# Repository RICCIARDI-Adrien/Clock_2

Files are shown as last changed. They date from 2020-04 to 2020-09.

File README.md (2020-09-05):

# Clock 2

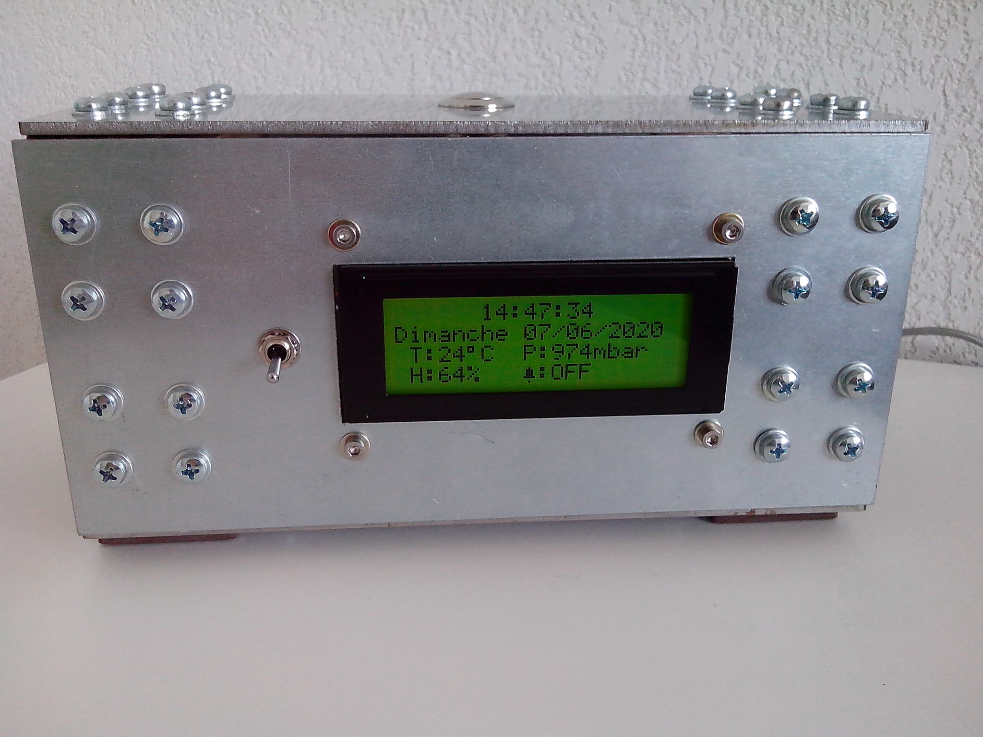
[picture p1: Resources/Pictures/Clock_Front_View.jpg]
Clock 2


Improved digital clock. First generation is [here](https://github.com/RICCIARDI-Adrien/Clock).  

New features :
* Improved temperature sensor.
* Humidity sensor.
* Pressure sensor.
* High accuracy temperature-compensated RTC.
* More compact, more industrial and more robust casing.
* A really simple interface made of 3 buttons to configure all clock settings (no more configuration through USB).

## Firmware

Microchip XC8 version 2.20 or above is required to build the firmware. Previous XC8 versions will work but the Celsius degree unit won't be displayed. This is due to a bug in XC8 escaped string characters parsing.

On a Linux system with XC8 installed and added to `PATH`, enter the following lines :
```
cd <repository directory>/Software
make
```

Resulting firmware file is `Firmware.hex`.

## Photo gallery

### PCB

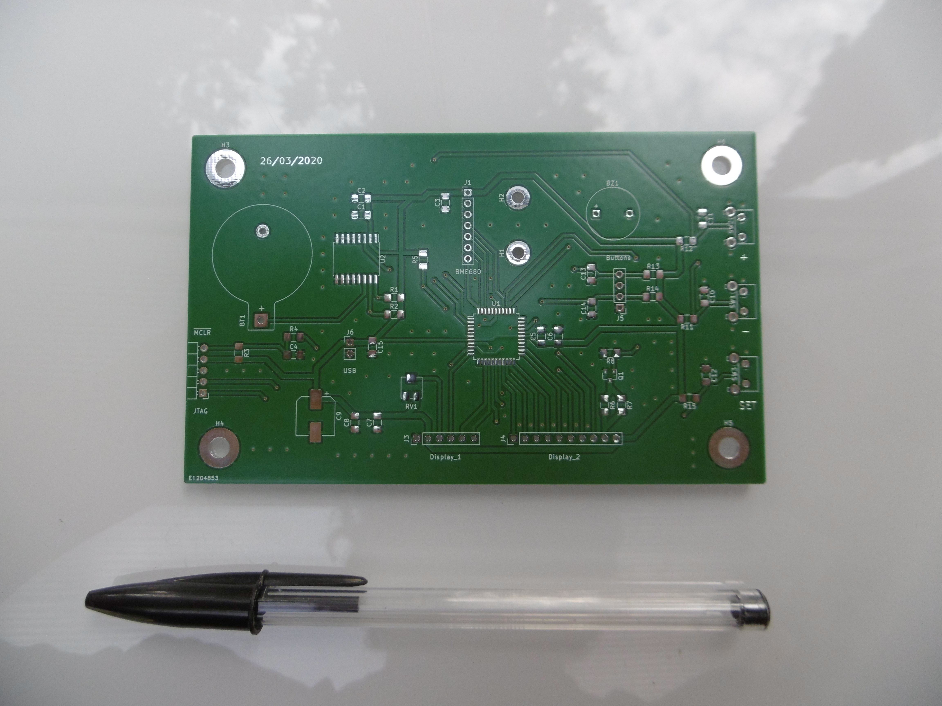
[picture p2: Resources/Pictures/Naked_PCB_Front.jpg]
Naked PCB front

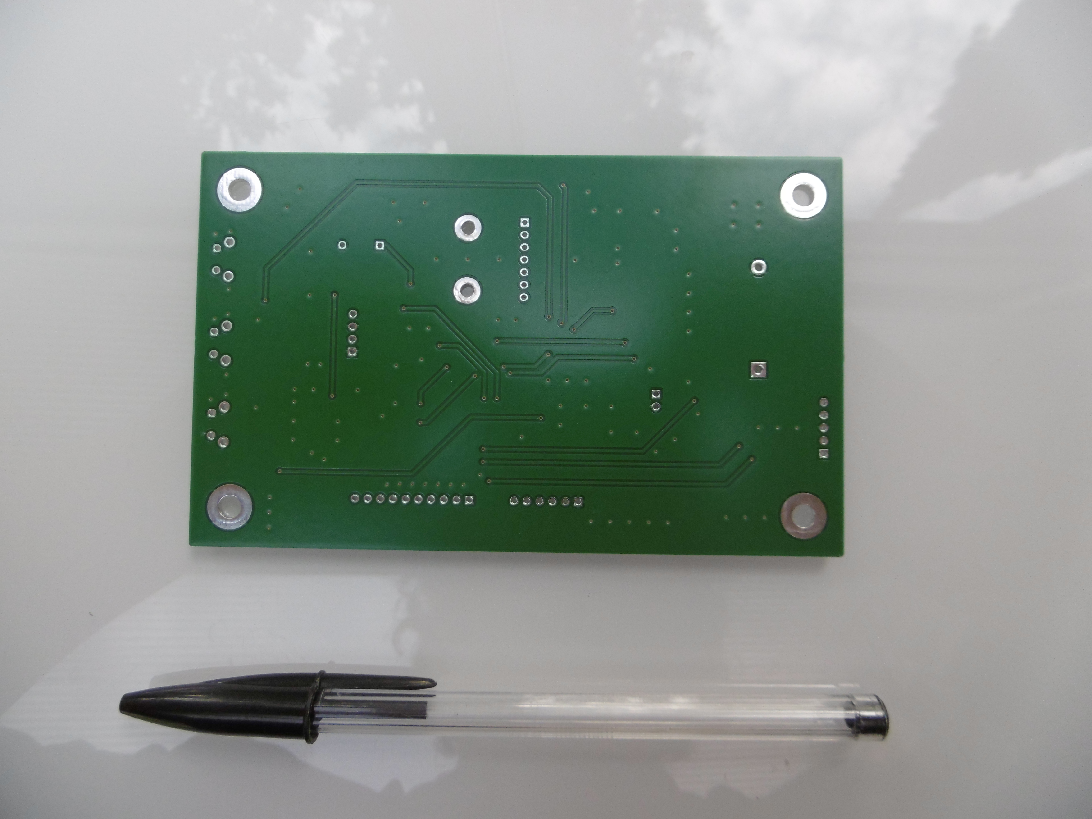
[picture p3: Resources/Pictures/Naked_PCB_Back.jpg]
Naked PCB back


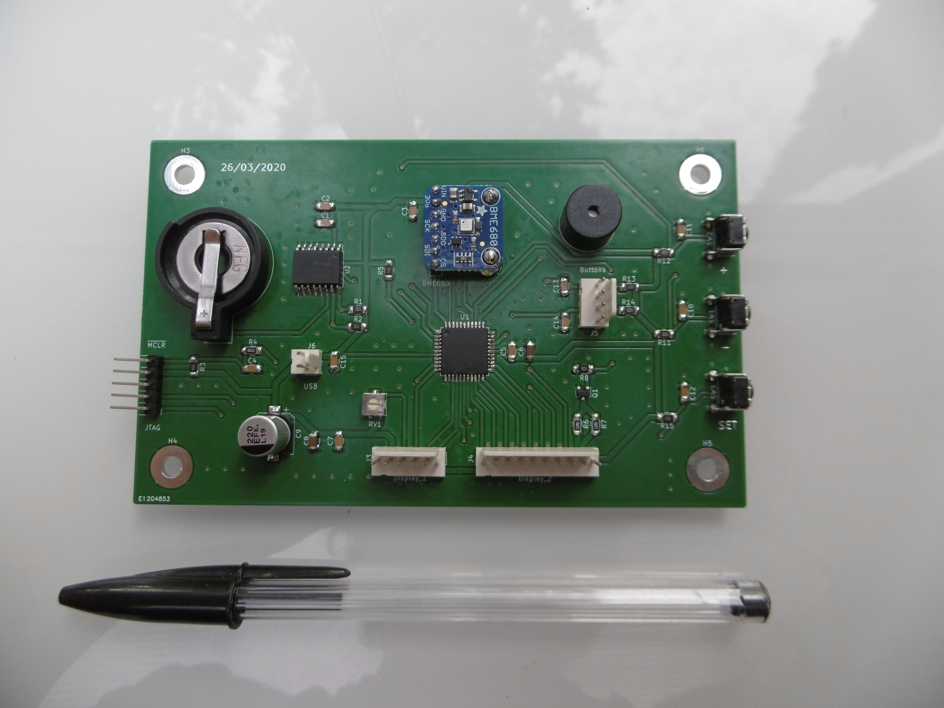
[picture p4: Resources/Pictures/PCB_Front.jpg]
PCB front

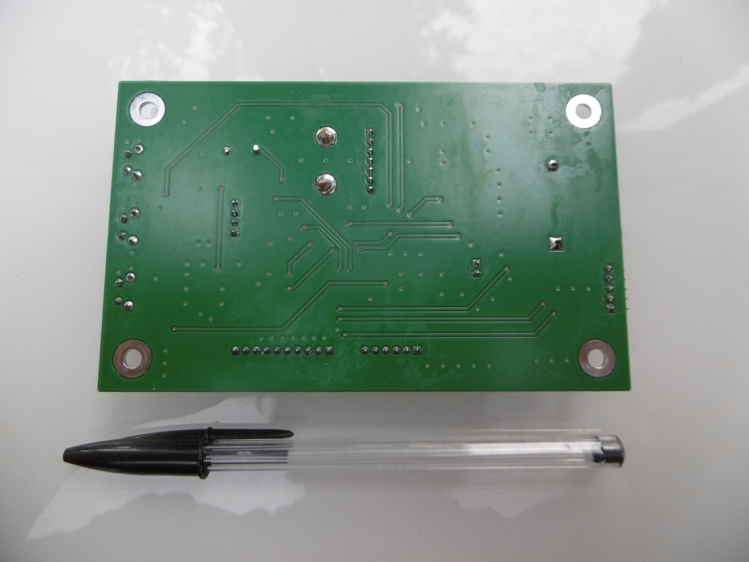
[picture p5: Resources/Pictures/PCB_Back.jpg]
PCB back


### Display

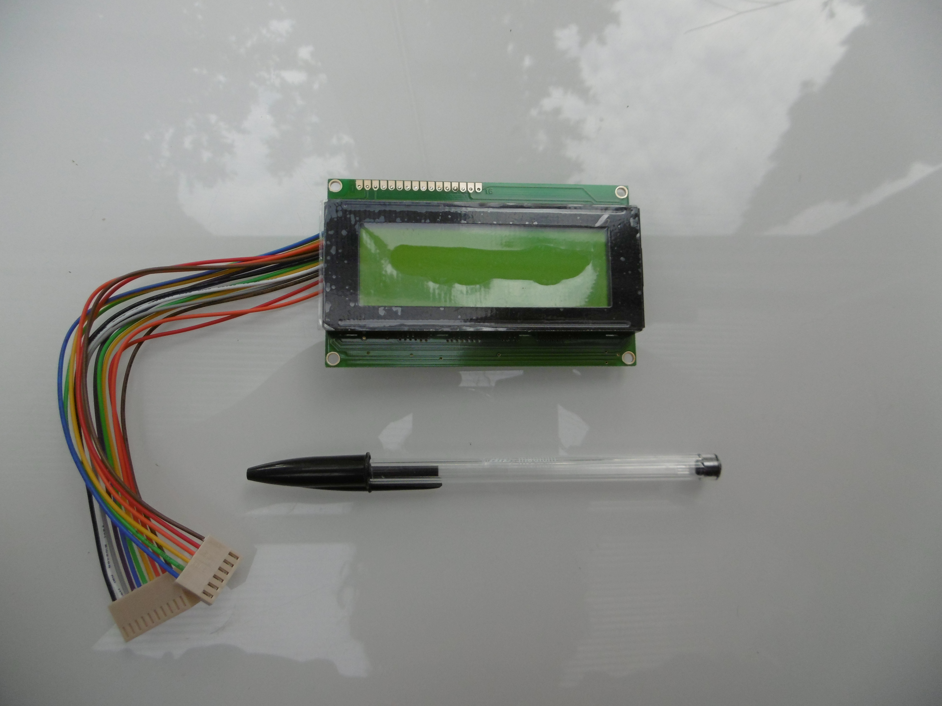
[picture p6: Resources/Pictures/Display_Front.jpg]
Display front

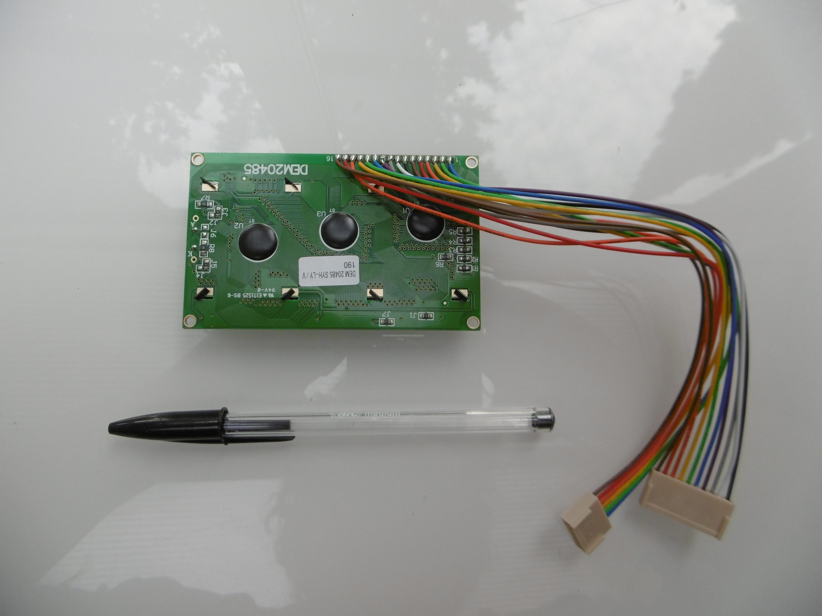
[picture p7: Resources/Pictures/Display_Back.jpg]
Display back


### Casing

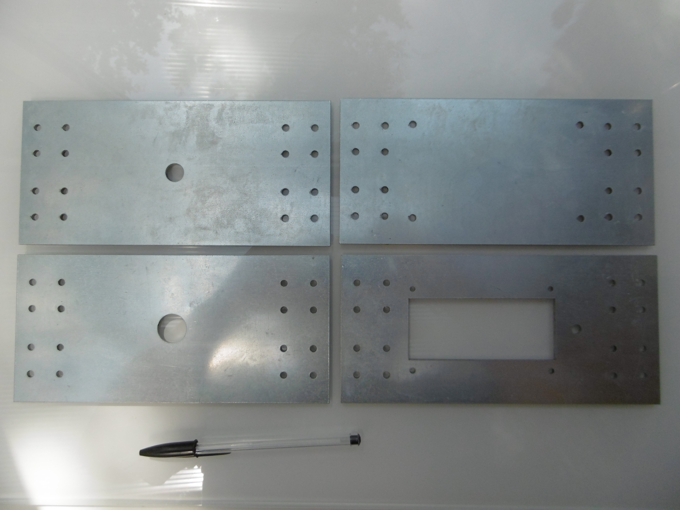
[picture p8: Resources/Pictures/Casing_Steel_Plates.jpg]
Casing steel plates


### Finished clock

Clock front view

Alarm stopping and display backlight button :
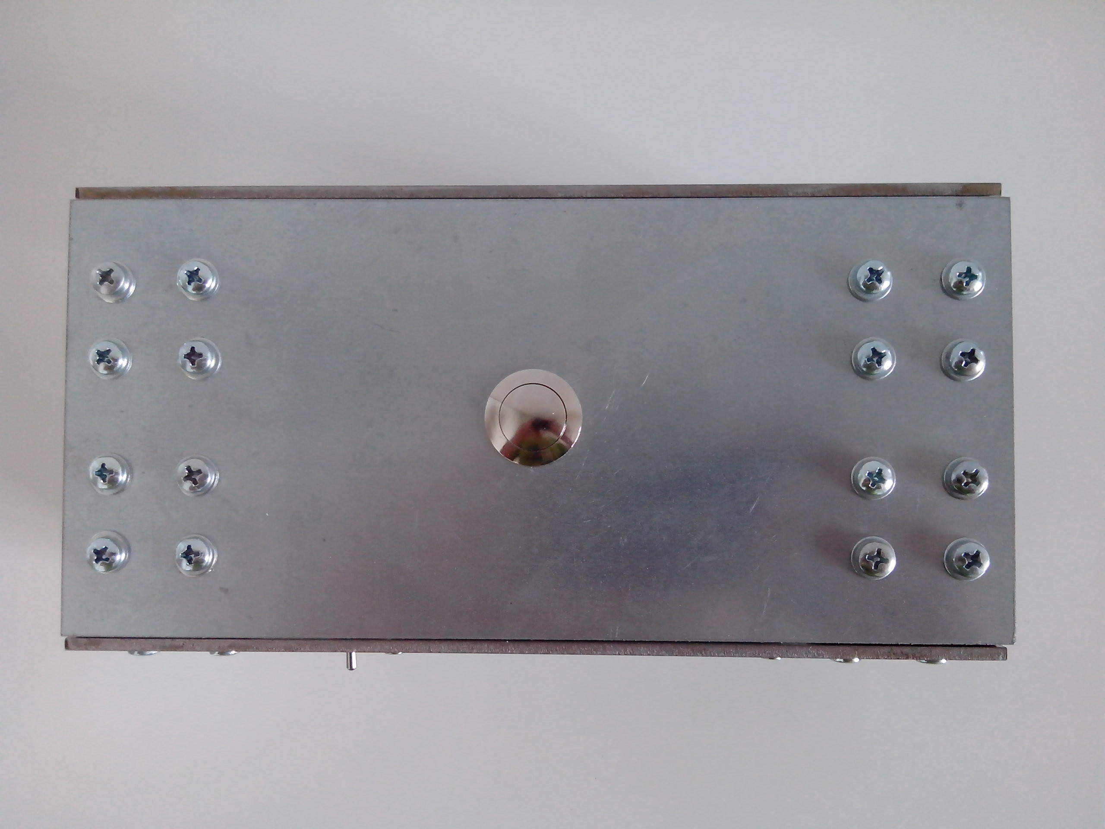
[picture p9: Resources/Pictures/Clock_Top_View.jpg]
Clock top view


Power supply USB connector :
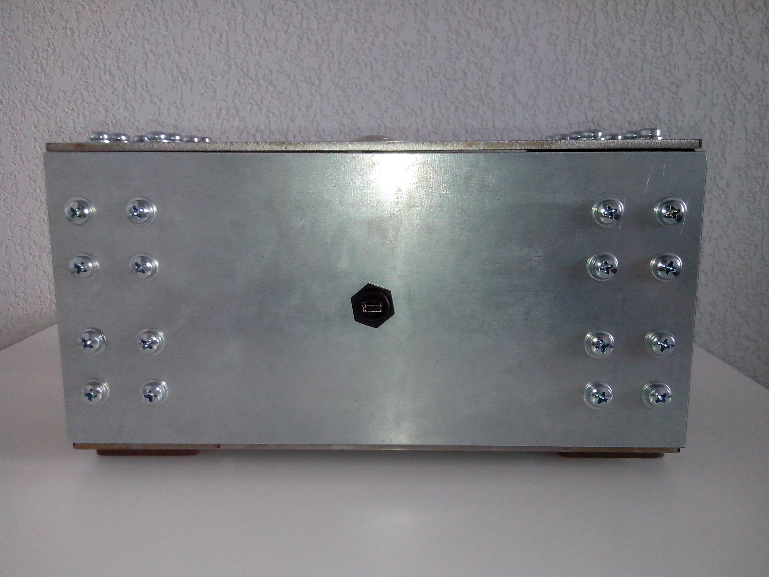
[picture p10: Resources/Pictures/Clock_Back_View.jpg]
Clock back view


Bottom protection pads :
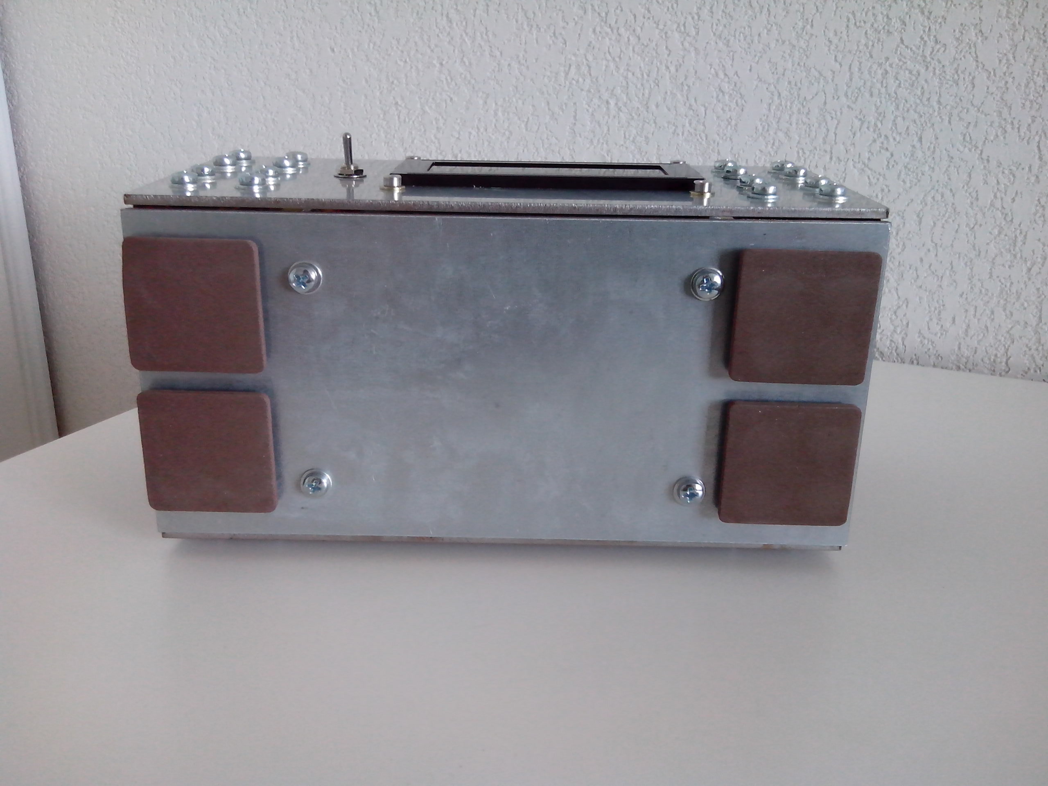
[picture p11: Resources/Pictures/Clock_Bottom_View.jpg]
Clock bottom view


Internal view (backup battery not yet fitted) :
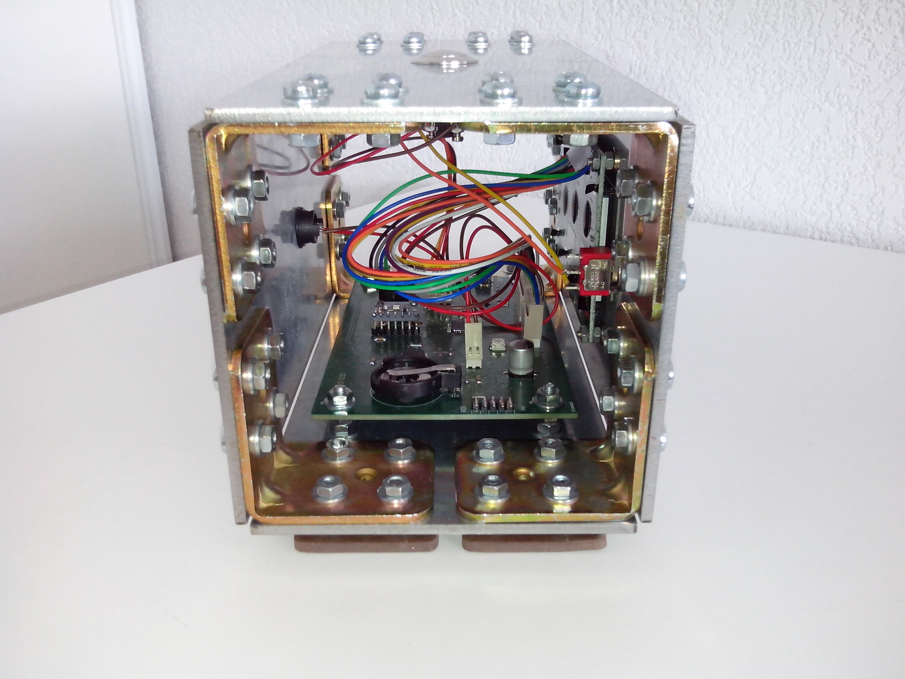
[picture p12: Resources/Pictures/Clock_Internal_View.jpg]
Clock internal view


## Views

### Main

```
+--------------------+
|      11:16:23      |
|Jeudi    19/03/2020 |
| T:23°C  P:1112mBar |
| H:68%   A:OFF      |
+--------------------+
```

```
+--------------------+
|       0:37:11      |
|Dimanche 06/09/2020 |
| T:27°C  P:983mBar  |
| H:50%   A:ON(08:30)|
+--------------------+
```

'A' stands for a bell symbol representing the current alarm state (enabled or disabled).

### Statistics

Press `+` button to reach temperature view.  
Press `-` button to reach humidity view (these views can be accessed in reverse order).

```
+--------------------+
|---- TEMPERATURE ---|
|Minimum : 23°C      |
|Maximum : 15°C      |
|                    |
+--------------------+
```

Press `Set` or `-` button to return to main view.  
Press `+` button to go to pressure view.

```
+--------------------+
|----- PRESSION -----|
|Minimum : 980mbar   |
|Maximum : 1002mbar  |
|                    |
+--------------------+
```

Press `Set` to immediately return to main view.  
Press `-` button to return to temperature view.  
Press `+` button to go to humidity view.

```
+--------------------+
|----- HUMIDITE -----|
|Minimum : 57%       |
|Maximum : 59%       |
|                    |
+--------------------+
```

Press `Set` or `+` button to return to main view.  
Press `-` button to return to pression view.

### Settings

Press `Set` button to reach this view.

```
+--------------------+
|-> Régler alarme    |
|   Régler heure     |
|   Régler date      |
|       Retour       |
+--------------------+
```
Select a menu entry using `+` and `-` buttons, then press `Set` button.

### Set alarm

```
+--------------------+
|--- HEURE ALARME ---|
| Heure : 7          |
| + et - pour régler |
| SET pour continuer |
+--------------------+
```
Press `+` and `-` buttons to choose an hour, then press `Set` button to continue.

```
+--------------------+
|-- MINUTES ALARME --|
| Minutes : 30       |
| + et - pour régler |
| SET pour continuer |
+--------------------+
```
Press `+` and `-` buttons to choose minutes value, then press `Set` button to return to settings menu.

### Set time

```
+--------------------+
|--- REGLER HEURE ---|
| Heure : 11         |
| + et - pour régler |
| SET pour continuer |
+--------------------+
```
Press `+` and `-` buttons to choose an hour, then press `Set` button to continue.

```
+--------------------+
|-- REGLER MINUTES --|
| Minutes : 26       |
| + et - pour régler |
| SET pour continuer |
+--------------------+
```
Press `+` and `-` buttons to choose minutes value, then press `Set` button to continue.

```
+--------------------+
|- REGLER SECONDES --|
| Secondes : 47      |
| + et - pour régler |
| SET pour continuer |
+--------------------+
```
Press `+` and `-` buttons to choose seconds value, then press `Set` button to return to settings menu.

### Set date

```
+--------------------+
|--- REGLER JOUR ----|
| Jour : 14          |
| + et - pour régler |
| SET pour continuer |
+--------------------+
```
Press `+` and `-` buttons to choose a day, then press `Set` button to continue.

```
+--------------------+
|--- REGLER MOIS ----|
| Mois : 3           |
| + et - pour régler |
| SET pour continuer |
+--------------------+
```
Press `+` and `-` buttons to choose a month, then press `Set` button to continue.

```
+--------------------+
|--- REGLER ANNEE ---|
| Année : 2020       |
| + et - pour régler |
| SET pour continuer |
+--------------------+
```
Press `+` and `-` buttons to choose a year, then press `Set` button to return to settings menu.

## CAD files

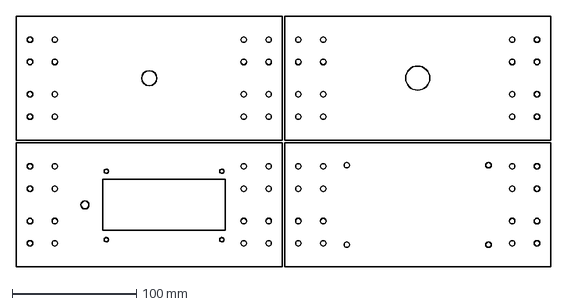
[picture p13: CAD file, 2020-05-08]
Casing/Casing.dxf
430.0 x 202.0 mm

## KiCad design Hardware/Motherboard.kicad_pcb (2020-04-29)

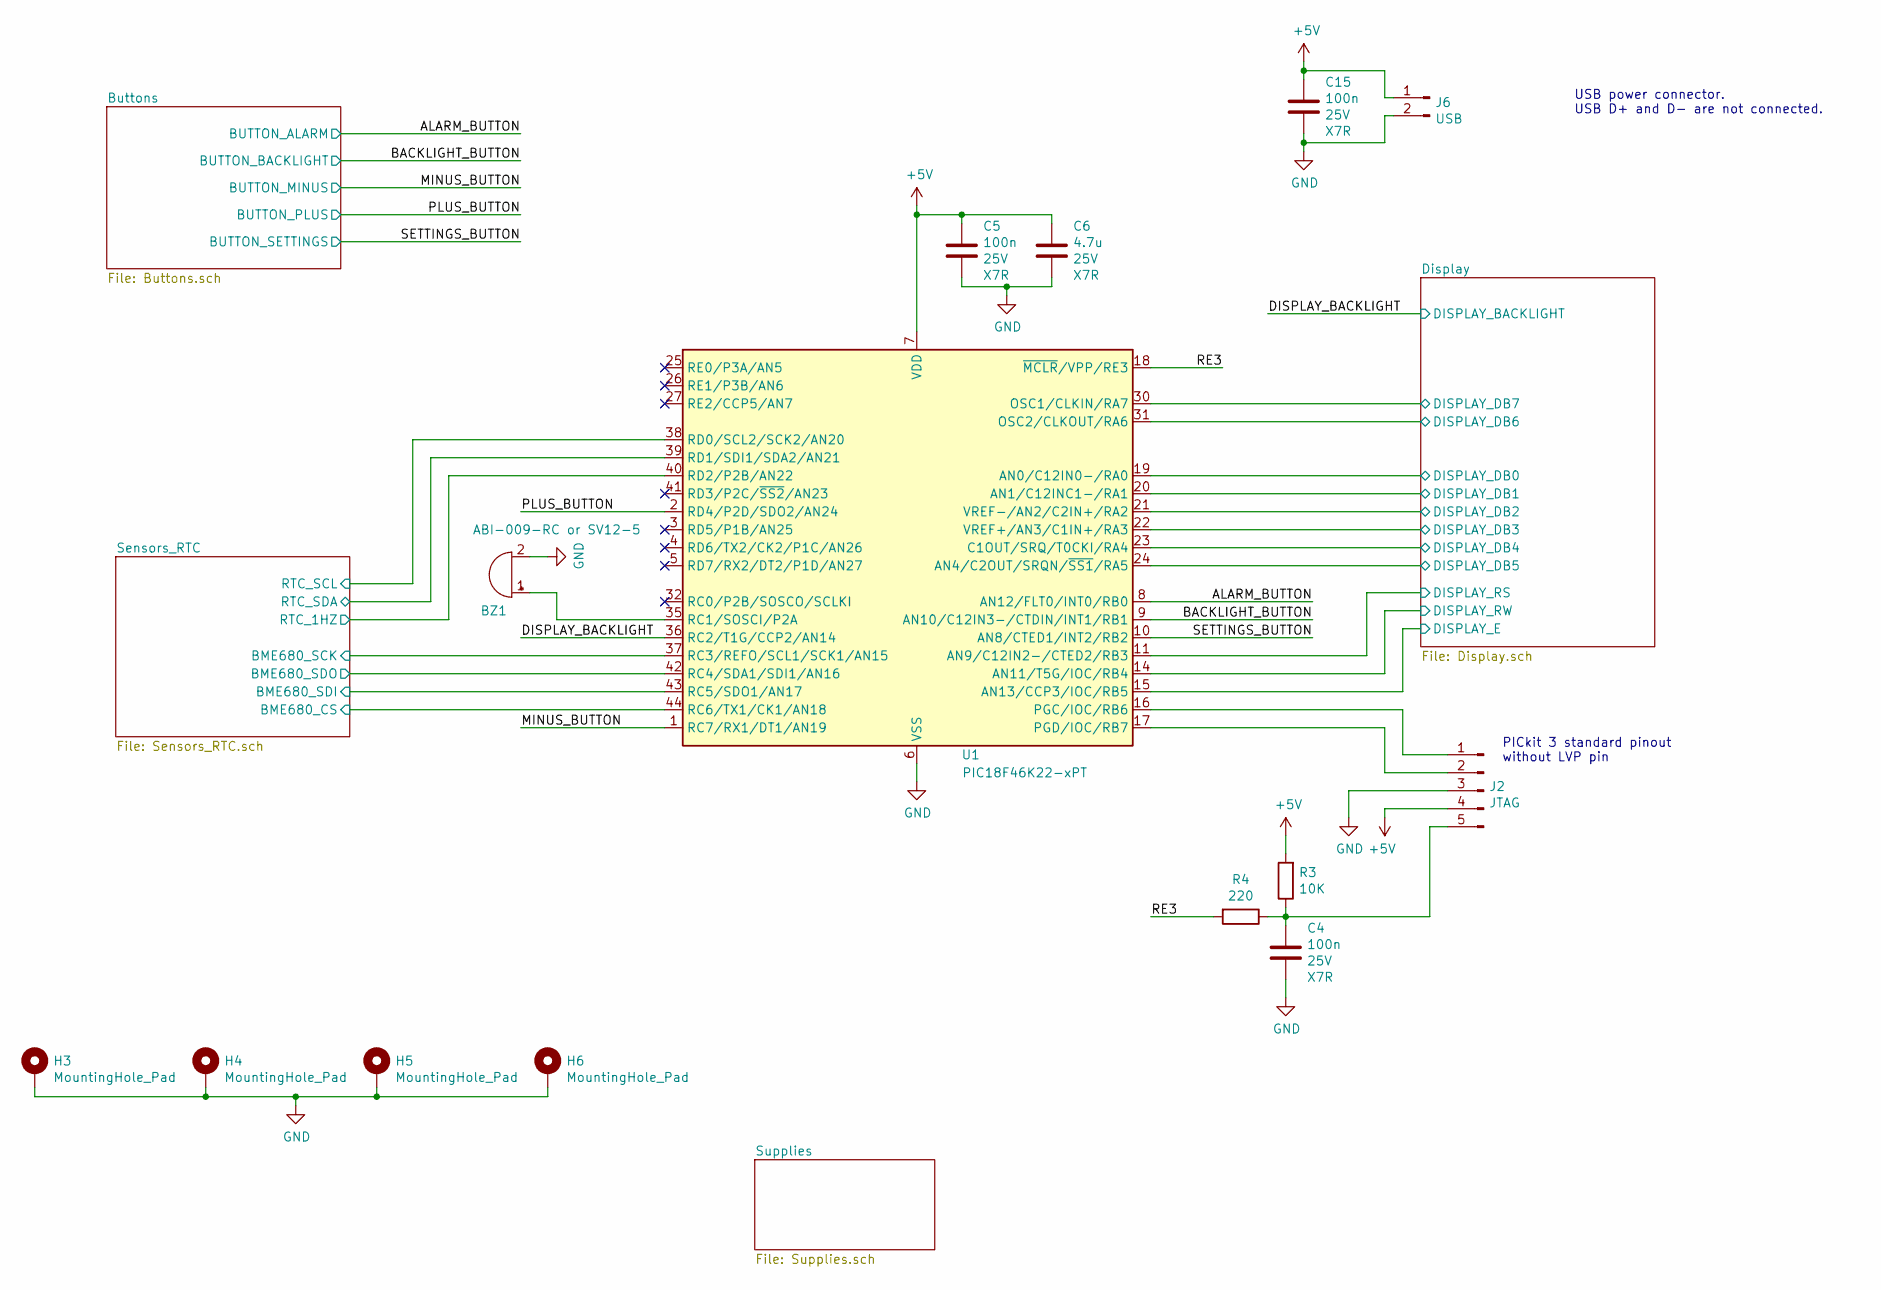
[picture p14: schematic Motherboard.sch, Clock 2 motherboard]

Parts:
BZ1: ABI-009-RC or SV12-5; MagneticBuzzer_ProSignal_ABI-009-RC
C4, C5, C15: 100n; C_1206_3216Metric_Pad1.42x1.75mm_HandSolder
C6: 4.7u; C_1206_3216Metric_Pad1.42x1.75mm_HandSolder
H3, H4, H5, H6: MountingHole_Pad; MountingHole_4.5mm_Pad
J2: JTAG; PinHeader_1x05_P2.54mm_Horizontal
J6: USB; PinHeader_1x02_P2.54mm_Vertical
R3: 10K; R_1206_3216Metric_Pad1.42x1.75mm_HandSolder
R4: 220; R_1206_3216Metric_Pad1.42x1.75mm_HandSolder
U1: PIC18F46K22-xPT; TQFP-44_10x10mm_P0.8mm

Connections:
+5V: C5.1, C6.1, C15.1, J2.4, J6.1, R3.2, U1.7 (VDD), U1.28 (VDD); also elsewhere on the board
/ALARM_BUTTON: U1.8 (AN12/FLT0/INT0/RB0); also elsewhere on the board
/BACKLIGHT_BUTTON: U1.9 (AN10/C12IN3-/CTDIN/INT1/RB1); also elsewhere on the board
/DISPLAY_BACKLIGHT: U1.36 (RC2/T1G/CCP2/AN14); also elsewhere on the board
/Display/DISPLAY_DB0: U1.19 (AN0/C12IN0-/RA0); also elsewhere on the board
/Display/DISPLAY_DB1: U1.20 (AN1/C12INC1-/RA1); also elsewhere on the board
/Display/DISPLAY_DB2: U1.21 (VREF-/AN2/C2IN+/RA2); also elsewhere on the board
/Display/DISPLAY_DB3: U1.22 (VREF+/AN3/C1IN+/RA3); also elsewhere on the board
/Display/DISPLAY_DB4: U1.23 (C1OUT/SRQ/T0CKI/RA4); also elsewhere on the board
/Display/DISPLAY_DB5: U1.24 (AN4/C2OUT/SRQN/~SS1~/RA5); also elsewhere on the board
/Display/DISPLAY_DB6: U1.31 (OSC2/CLKOUT/RA6); also elsewhere on the board
/Display/DISPLAY_DB7: U1.30 (OSC1/CLKIN/RA7); also elsewhere on the board
/Display/DISPLAY_E: U1.15 (AN13/CCP3/IOC/RB5); also elsewhere on the board
/Display/DISPLAY_RS: U1.11 (AN9/C12IN2-/CTED2/RB3); also elsewhere on the board
/Display/DISPLAY_RW: U1.14 (AN11/T5G/IOC/RB4); also elsewhere on the board
/MINUS_BUTTON: U1.1 (RC7/RX1/DT1/AN19); also elsewhere on the board
/PLUS_BUTTON: U1.2 (RD4/P2D/SDO2/AN24); also elsewhere on the board
/RE3: R4.2, U1.18 (~MCLR~/VPP/RE3)
/SETTINGS_BUTTON: U1.10 (AN8/CTED1/INT2/RB2); also elsewhere on the board
/Sensors_RTC/BME680_CS: U1.44 (RC6/TX1/CK1/AN18); also elsewhere on the board
/Sensors_RTC/BME680_SCK: U1.37 (RC3/REFO/SCL1/SCK1/AN15); also elsewhere on the board
/Sensors_RTC/BME680_SDI: U1.43 (RC5/SDO1/AN17); also elsewhere on the board
/Sensors_RTC/BME680_SDO: U1.42 (RC4/SDA1/SDI1/AN16); also elsewhere on the board
/Sensors_RTC/RTC_1HZ: U1.40 (RD2/P2B/AN22); also elsewhere on the board
/Sensors_RTC/RTC_SCL: U1.38 (RD0/SCL2/SCK2/AN20); also elsewhere on the board
/Sensors_RTC/RTC_SDA: U1.39 (RD1/SDI1/SDA2/AN21); also elsewhere on the board
GND: BZ1.2 (+), C4.2, C5.2, C6.2, C15.2, H3.1, H4.1, H5.1, H6.1, J2.3, J6.2, U1.6 (VSS), U1.29 (VSS); also elsewhere on the board
unnamed: BZ1.1 (-), U1.35 (RC1/SOSCI/P2A)
unnamed: C4.1, J2.5, R3.1, R4.1
unnamed: J2.1, U1.16 (PGC/IOC/RB6)
unnamed: J2.2, U1.17 (PGD/IOC/RB7)

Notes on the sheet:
PICkit 3 standard pinout without LVP pin
USB power connector. USB D+ and D- are not connected.

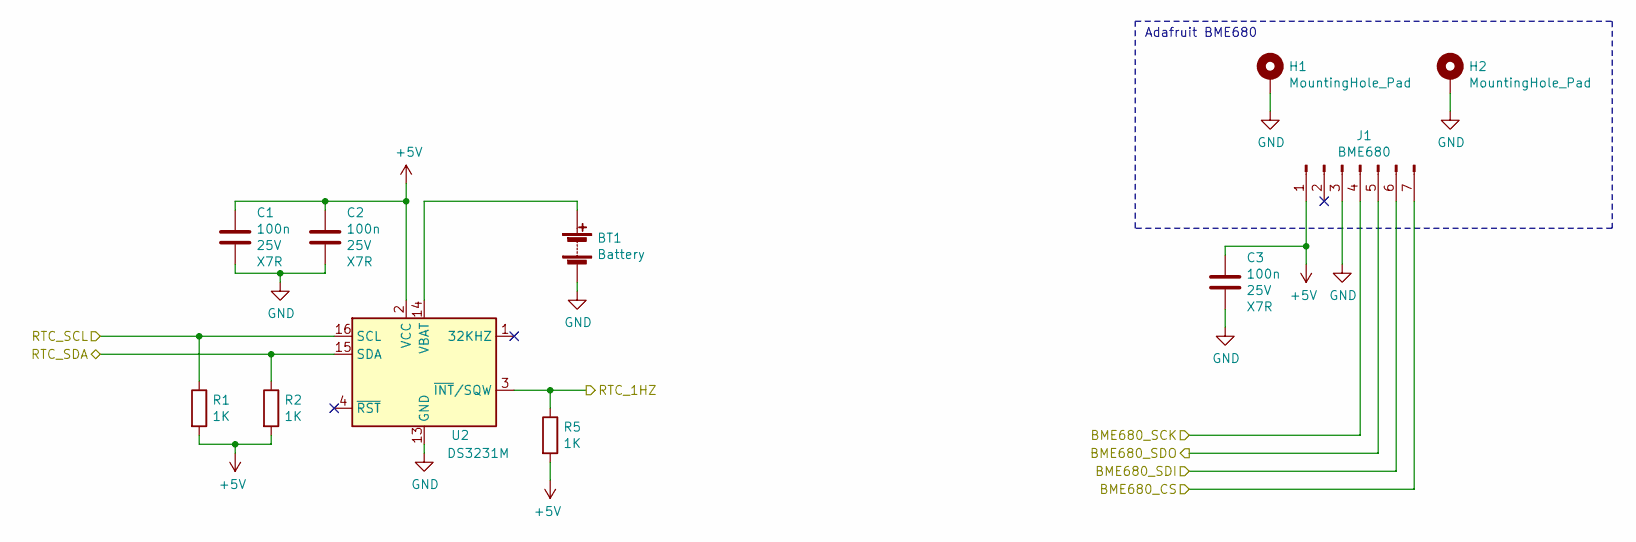
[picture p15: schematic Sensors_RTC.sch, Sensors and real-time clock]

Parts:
BT1: Battery; BatteryHolder_Keystone_103_1x20mm
C1, C2, C3: 100n; C_1206_3216Metric_Pad1.42x1.75mm_HandSolder
H1, H2: MountingHole_Pad; MountingHole_2.7mm_Pad
J1: BME680; PinHeader_1x07_P2.54mm_Vertical
R1, R2, R5: 1K; R_1206_3216Metric_Pad1.42x1.75mm_HandSolder
U2: DS3231M; SOIC-16W_7.5x10.3mm_P1.27mm

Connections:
+5V: C1.2, C2.2, C3.2, J1.1, R1.2, R2.2, R5.2, U2.2 (VCC); also elsewhere on the board
/Sensors_RTC/BME680_CS: J1.7; also elsewhere on the board
/Sensors_RTC/BME680_SCK: J1.4; also elsewhere on the board
/Sensors_RTC/BME680_SDI: J1.6; also elsewhere on the board
/Sensors_RTC/BME680_SDO: J1.5; also elsewhere on the board
/Sensors_RTC/RTC_1HZ: R5.1, U2.3 (~INT~/SQW); also elsewhere on the board
/Sensors_RTC/RTC_SCL: R1.1, U2.16 (SCL); also elsewhere on the board
/Sensors_RTC/RTC_SDA: R2.1, U2.15 (SDA); also elsewhere on the board
GND: BT1.2 (-), C1.1, C2.1, C3.1, H1.1, H2.1, J1.3, U2.5 (GND), U2.6 (GND), U2.7 (GND), U2.8 (GND), U2.9 (GND), U2.10 (GND), U2.11 (GND), U2.12 (GND), U2.13 (GND); also elsewhere on the board
unnamed: BT1.1 (+), U2.14 (VBAT)

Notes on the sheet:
Adafruit BME680

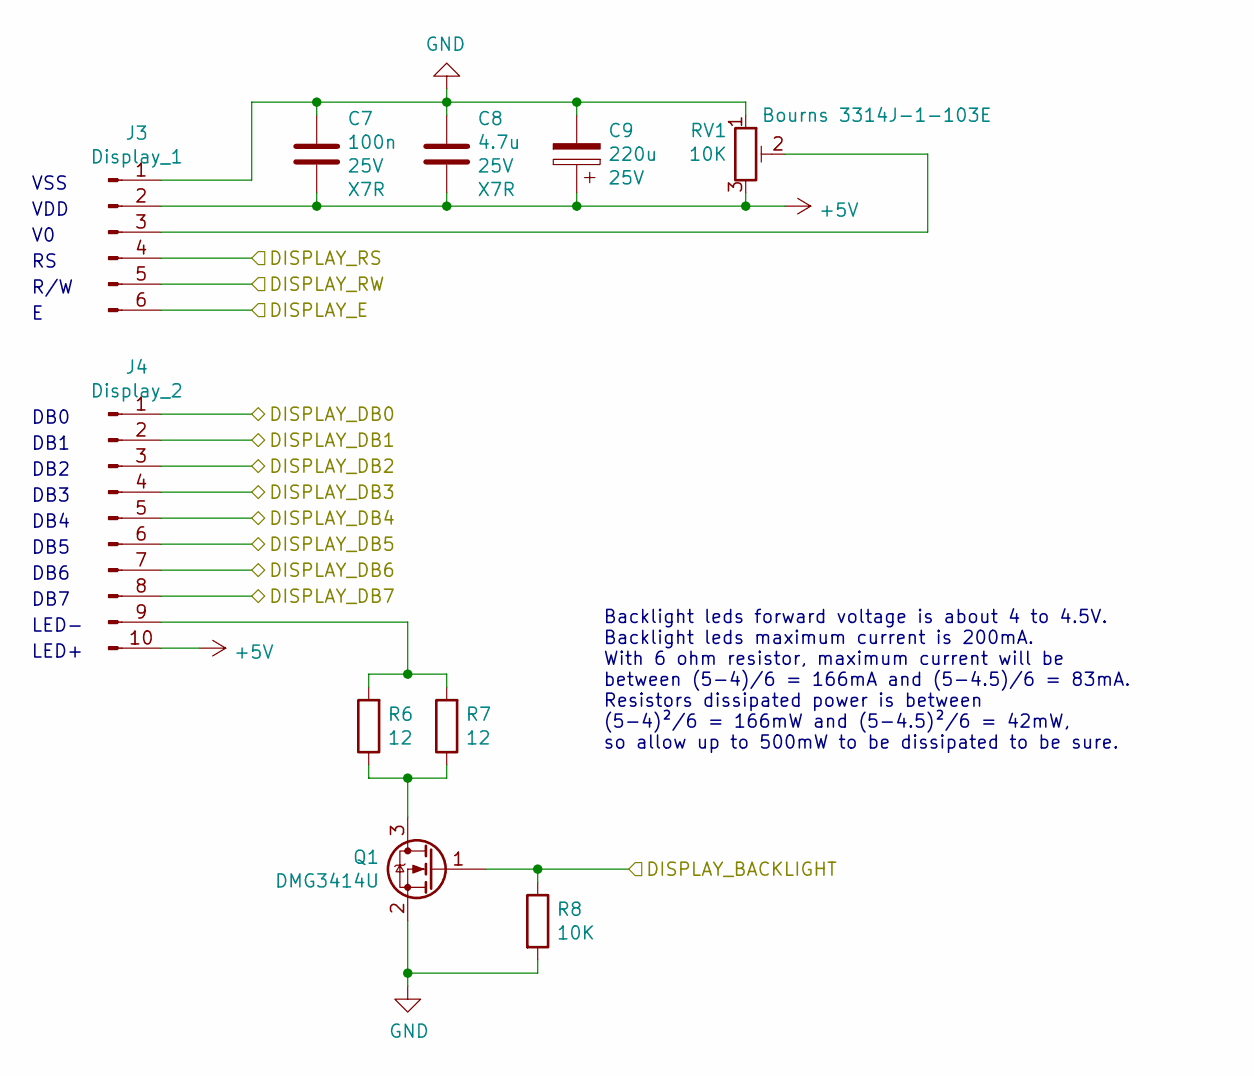
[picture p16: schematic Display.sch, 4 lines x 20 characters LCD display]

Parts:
C7: 100n; C_1206_3216Metric_Pad1.42x1.75mm_HandSolder
C8: 4.7u; C_1206_3216Metric_Pad1.42x1.75mm_HandSolder
C9: 220u; CP_Elec_8x10.5
J3: Display_1; PinHeader_1x06_P2.54mm_Vertical
J4: Display_2; PinHeader_1x10_P2.54mm_Vertical
Q1: DMG3414U; SOT-23
R6, R7: 12; R_1206_3216Metric_Pad1.42x1.75mm_HandSolder
R8: 10K; R_1206_3216Metric_Pad1.42x1.75mm_HandSolder
RV1: 10K; Potentiometer_Bourns_3314J_Vertical

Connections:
+5V: C7.2, C8.2, C9.1, J3.2, J4.10, RV1.3; also elsewhere on the board
/DISPLAY_BACKLIGHT: Q1.1 (G), R8.1; also elsewhere on the board
/Display/DISPLAY_DB0: J4.1; also elsewhere on the board
/Display/DISPLAY_DB1: J4.2; also elsewhere on the board
/Display/DISPLAY_DB2: J4.3; also elsewhere on the board
/Display/DISPLAY_DB3: J4.4; also elsewhere on the board
/Display/DISPLAY_DB4: J4.5; also elsewhere on the board
/Display/DISPLAY_DB5: J4.6; also elsewhere on the board
/Display/DISPLAY_DB6: J4.7; also elsewhere on the board
/Display/DISPLAY_DB7: J4.8; also elsewhere on the board
/Display/DISPLAY_E: J3.6; also elsewhere on the board
/Display/DISPLAY_RS: J3.4; also elsewhere on the board
/Display/DISPLAY_RW: J3.5; also elsewhere on the board
GND: C7.1, C8.1, C9.2, J3.1, Q1.2 (S), R8.2, RV1.1; also elsewhere on the board
unnamed: J3.3, RV1.2
unnamed: J4.9, R6.2, R7.2
unnamed: Q1.3 (D), R6.1, R7.1

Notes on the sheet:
DB0
DB1
DB2
DB3
DB4
DB5
DB6
DB7
VSS
VDD
R/W
LED-
LED+
Backlight leds forward voltage is about 4 to 4.5V. Backlight leds maximum current is 200mA. With 6 ohm resistor, maximum current will be between (5-4)/6 = 166mA and (5-4.5)/6 = 83mA. Resistors dissipated power is between (5-4)²/6 = 166mW and (5-4.5)²/6 = 42mW, so allow up to 500mW to be dissipated 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

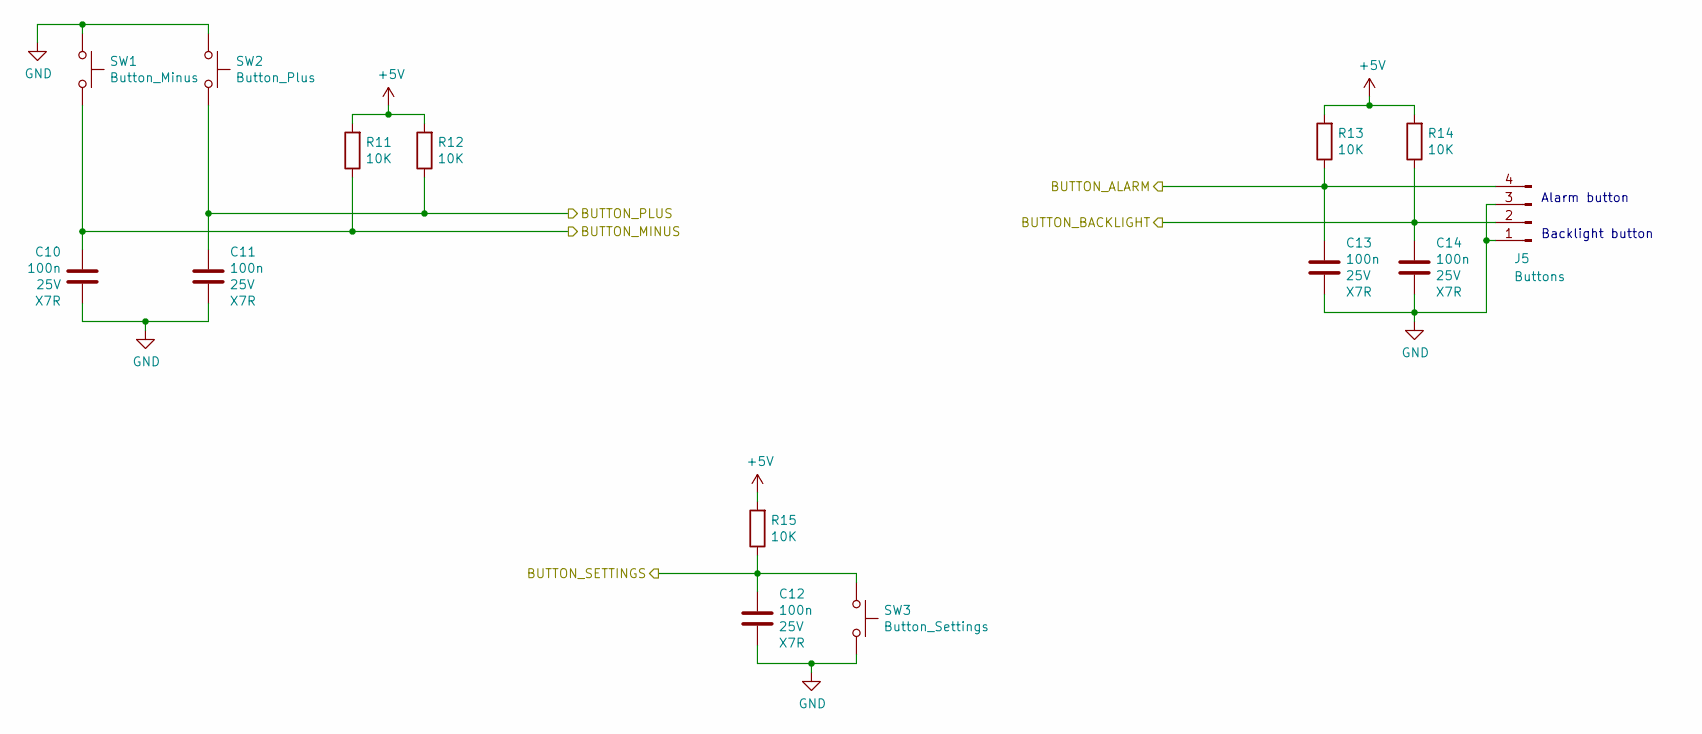
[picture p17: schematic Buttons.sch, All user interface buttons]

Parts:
C10, C11, C12, C13, C14: 100n; C_1206_3216Metric_Pad1.42x1.75mm_HandSolder
J5: Buttons; PinHeader_1x04_P2.54mm_Vertical
R11, R12, R13, R14, R15: 10K; R_1206_3216Metric_Pad1.42x1.75mm_HandSolder
SW1: Button_Minus; SW_Tactile_SKHH_Angled
SW2: Button_Plus; SW_Tactile_SKHH_Angled
SW3: Button_Settings; SW_Tactile_SKHH_Angled

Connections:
+5V: R11.2, R12.2, R13.2, R14.2, R15.2; also elsewhere on the board
/ALARM_BUTTON: C13.2, J5.4, R13.1; also elsewhere on the board
/BACKLIGHT_BUTTON: C14.2, J5.2, R14.1; also elsewhere on the board
/MINUS_BUTTON: C10.2, R11.1, SW1.2; also elsewhere on the board
/PLUS_BUTTON: C11.2, R12.1, SW2.2; also elsewhere on the board
/SETTINGS_BUTTON: C12.2, R15.1, SW3.2; also elsewhere on the board
GND: C10.1, C11.1, C12.1, C13.1, C14.1, J5.1, J5.3, SW1.1, SW2.1, SW3.1; also elsewhere on the board

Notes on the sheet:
Alarm button
Backlight button

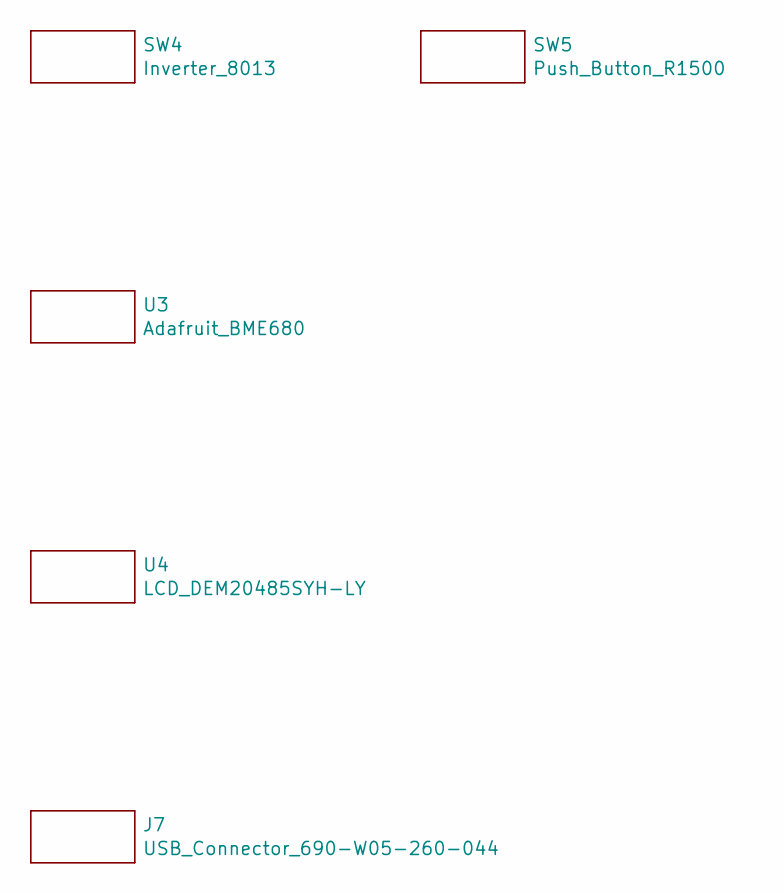
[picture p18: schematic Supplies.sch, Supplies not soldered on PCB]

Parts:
J7: USB_Connector_690-W05-260-044; Supply_Part
SW4: Inverter_8013; Supply_Part
SW5: Push_Button_R1500; Supply_Part
U3: Adafruit_BME680; Supply_Part
U4: LCD_DEM20485SYH-LY; Supply_Part

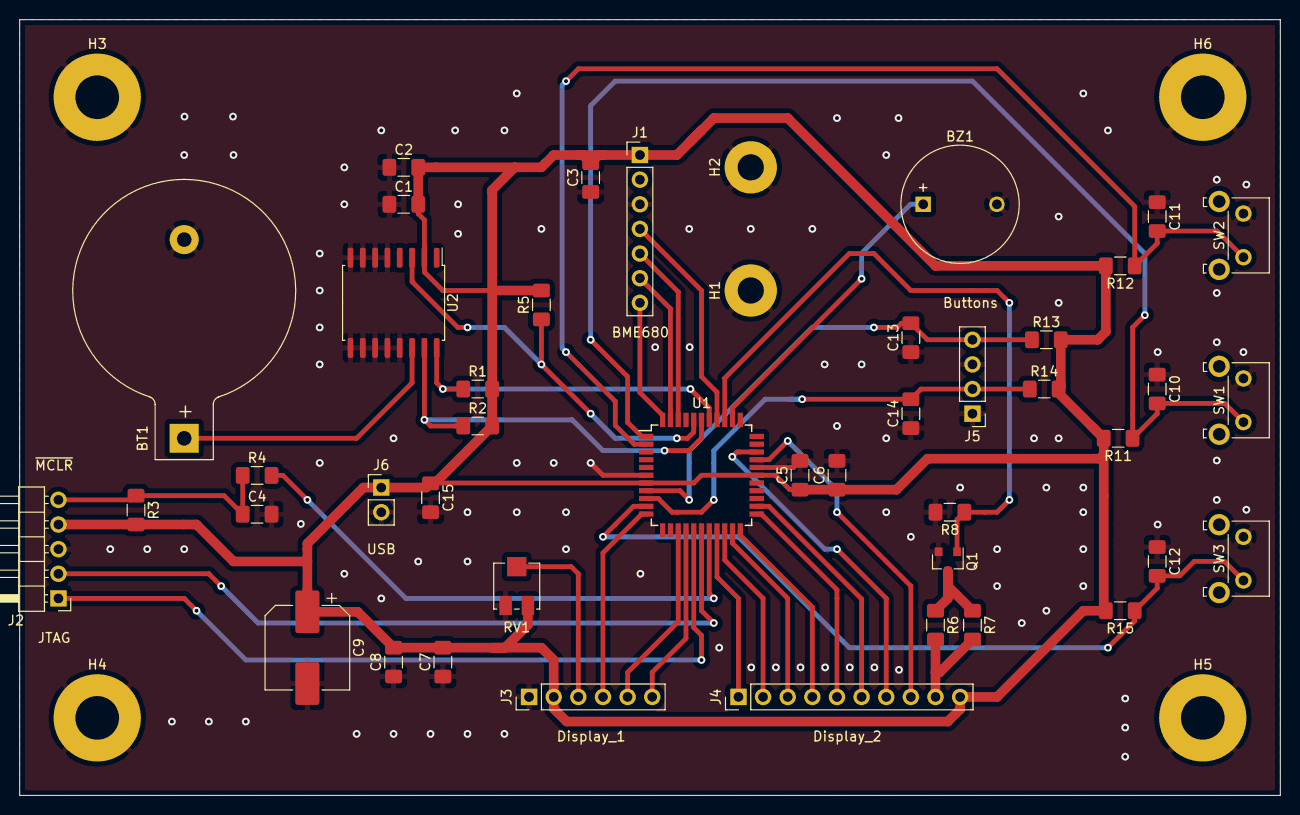
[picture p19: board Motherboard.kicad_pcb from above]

Board: 2 copper layers, 130.0 x 80.0 mm, 54 parts (0 on the bottom side), 35 nets.

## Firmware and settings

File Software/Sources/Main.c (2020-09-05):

/** @file Main.c
 * Clock entry point and main loop.
 * @author Adrien RICCIARDI
 */
#include <Buttons.h>
#include <Display.h>
#include <Ring.h>
#include <RTC.h>
#include <Sensors.h>
#include <string.h>
#include <xc.h>

//-------------------------------------------------------------------------------------------------
// Microcontroller configuration
//-------------------------------------------------------------------------------------------------
// CONFIG1H register
#pragma config FOSC = INTIO67, PLLCFG = ON, PRICLKEN = ON, FCMEN = OFF, IESO = OFF // Use internal oscillator, enable PLL, enable primary clock, disable fail-safe clock monitor, disable oscillator switchover mode
// CONFIG2L register
#pragma config PWRTEN = ON, BOREN = SBORDIS, BORV = 285 // Enable power up timer, enable brown-out reset in hardware only (so it can't be disabled by software), set highest value for brown-out voltage (2.85V)
// CONFIG2H register
#pragma config WDTEN = OFF // Disable watchdog timer
// CONFIG3H register
#pragma config CCP2MX = PORTC1, PBADEN = OFF, CCP3MX = PORTB5, HFOFST = OFF, MCLRE = EXTMCLR // Connect CCP2 module to RC1 pin, port B pin 5..0 are configured as digital I/O on reset, connect CCP3 module to RB5 pin (this CCP module is not used), wait for the oscillator to become stable before starting code execution, enable MCLR pin
// CONFIG4L register
#pragma config STVREN = ON, LVP = OFF, XINST = OFF, DEBUG = OFF // Reset on stack underflow or overflow, disable single supply ICSP, disable extended instruction set, disable background debug
// CONFIG5L register
#pragma config CP0 = OFF, CP1 = OFF // Disable all code protections
// CONFIG5H register
#pragma config CPB = OFF, CPD = OFF // Disable boot block code protection, disable data EEPROM code protection
// CONFIG6L register
#pragma config WRT0 = OFF, WRT1 = OFF // Disable all write protections
// CONFIG6H register
#pragma config WRTC = OFF, WRTB = OFF, WRTD = OFF // Disable configuration registers write protection, disable boot block write protection, disable data EEPROM write protection
// CONFIG7L register
#pragma config EBTR0 = OFF, EBTR1 = OFF // Disable all table read protections
// CONFIG7H register
#pragma config EBTRB = OFF // Disable boot block table read protection

//--------------------------------------------------------------------------------------------------
// Private variables
//--------------------------------------------------------------------------------------------------
/** The string corresponding to each day index. */
static char *Pointer_Main_String_Day_Names[] =
{
	"", // Index 0 does not exist
	"Dimanche",
	"Lundi   ",
	"Mardi   ",
	"Mercredi",
	"Jeudi   ",
	"Vendredi",
	"Samedi  "
};

/** Hold the least sampled values since clock power on. */
static TSensorsMeasures Main_Minimum_Measures = // Initialize each value with the biggest impossible value, so any sampled value will be lesser
{
	127,
	32767,
	101
};

/** Hold the last currently sampled values. */
static TSensorsMeasures Main_Current_Measures;

/** Hold the greatest sampled values since clock power on. */
static TSensorsMeasures Main_Maximum_Measures = // Initialize each value with the smallest impossible value, so any sampled value will be greater
{
	-128,
	-32768,
	0
};

//-------------------------------------------------------------------------------------------------
// Private functions
//-------------------------------------------------------------------------------------------------
/** Entry point for all high priority interrupts. */
static void __interrupt(high_priority) MainInterruptHandlerHighPriority(void)
{
	// Play ring melody
	if (RING_HAS_INTERRUPT_FIRED()) RingInterruptHandler();
}

/** Entry point for all low priority interrupts. */
static void __interrupt(low_priority) MainInterruptHandlerLowPriority(void)
{
	// Detect backlight button press
	if (BUTTONS_HAS_INTERRUPT_FIRED()) ButtonsInterruptHandler();

	// Turn display backlight off
	if (DISPLAY_HAS_INTERRUPT_FIRED()) DisplayInterruptHandler();
}

/** Convert a one-byte Binary Coded Decimal number to two ASCII characters.
 * @param BCD_Number The BCD number to convert.
 * @param Pointer_Tens_Character On output, contain the binary value of the number's tens.
 * @param Pointer_Units_Character On output, contain the binary value of the number's units.
 */
static void MainConvertBCDToASCII(unsigned char BCD_Number, unsigned char *Pointer_Tens_Character, unsigned char *Pointer_Units_Character)
{
	*Pointer_Tens_Character = (BCD_Number >> 4) + '0';
	*Pointer_Units_Character = (BCD_Number & 0x0F) + '0';
}

/** Convert a BCD-encoded number into its binary representation.
 * @param BCD_Number The BCD number to convert to binary.
 * @return The corresponding binary number.
 */
static unsigned char MainConvertBCDToBinary(unsigned char BCD_Number)
{
	unsigned char Tens, Units;
	
	// Extract tens and units
	Tens = BCD_Number >> 4;
	Units = BCD_Number & 0x0F;
	
	return (Tens * 10) + Units;
}

/** Allow to select a precise number in a specified interval using the menu buttons.
 * @param Pointer_String_View_Title The view title, displayed on the first display line.
 * @param Pointer_String_Text The text displayed before the number to select.
 * @param Minimum_Value The minimum allowed value (included). When a lower value is requested, the selected number wraps to its maximum value.
 * @param Maximum_Value The maximum allowed value (included). When a higher value is requested, the selected number wraps to its minimum value.
 * @param Current_Value The value to display when entering the view.
 * @return The selected number.
 */
static unsigned short MainShowNumberSelectionView(char *Pointer_String_View_Title, char *Pointer_String_Text, unsigned short Minimum_Value, unsigned short Maximum_Value, unsigned short Current_Value)
{
	unsigned char Text_Length;
	
	// Display strings that won't change
	DisplayClear();
	// Title
	DisplayWriteString(Pointer_String_View_Title);
	// Text
	DisplaySetCursorLocation(DISPLAY_CURSOR_LOCATION_LINE_2);
	DisplayWriteString(Pointer_String_Text);
	// Help
	DisplaySetCursorLocation(DISPLAY_CURSOR_LOCATION_LINE_3 + 1);
	DisplayWriteString("+ et - pour r\001gler");
	DisplaySetCursorLocation(DISPLAY_CURSOR_LOCATION_LINE_4 + 1);
	DisplayWriteString("SET pour continuer");
	
	// Make sure current value is in allowed range
	if ((Current_Value < Minimum_Value) || (Current_Value > Maximum_Value)) Current_Value = Minimum_Value;
	
	// Handle number selection
	Text_Length = strlen(Pointer_String_Text); // Cache text string length
	while (1)
	{
		// Clear number previous trace
		DisplaySetCursorLocation(DISPLAY_CURSOR_LOCATION_LINE_2 + Text_Length);
		DisplayWriteString("     "); // There are up to 5 digits in a 16-bit number
		
		// Display number
		DisplaySetCursorLocation(DISPLAY_CURSOR_LOCATION_LINE_2 + Text_Length);
		DisplayWriteNumber(Current_Value);
		
		// Handle user inputs
		switch (ButtonsWaitMenuButtonPress())
		{
			case BUTTONS_MENU_ID_MINUS:
				if (Current_Value == Minimum_Value) Current_Value = Maximum_Value;
				else Current_Value--;
				break;
			
			// Increase number
			case BUTTONS_MENU_ID_PLUS:
				if (Current_Value >= Maximum_Value) Current_Value = Minimum_Value;
				else Current_Value++;
				break;
				
			case BUTTONS_MENU_ID_SET:
				return Current_Value;
		}
	}
}

/** Default view, displays time, date and sensors measures. */
static inline void MainShowDefaultView(void)
{
	TRTCTime Time, Time_Alarm;
	TRTCDate Date;
	unsigned char Tens_Character, Units_Character;
	
	// Display time
	RTCGetTime(&Time);
	DisplaySetCursorLocation(6); // Center time on the first line
	// Display hours
	MainConvertBCDToASCII(Time.Hours, &Tens_Character, &Units_Character);
	if (Tens_Character == '0') Tens_Character = ' '; // Do not display the leading zero
	DisplayWriteCharacter(Tens_Character);
	DisplayWriteCharacter(Units_Character);
	DisplayWriteCharacter(':');
	// Display minutes
	MainConvertBCDToASCII(Time.Minutes, &Tens_Character, &Units_Character);
	DisplayWriteCharacter(Tens_Character);
	DisplayWriteCharacter(Units_Character);
	DisplayWriteCharacter(':');
	// Display seconds
	MainConvertBCDToASCII(Time.Seconds, &Tens_Character, &Units_Character);
	DisplayWriteCharacter(Tens_Character);
	DisplayWriteCharacter(Units_Character);
	
	// Display date
	RTCGetDate(&Date);
	DisplaySetCursorLocation(DISPLAY_CURSOR_LOCATION_LINE_2);
	// Display the day name (all names are padded with spaces to be sure to erase a previous name that was longer)
	DisplayWriteString(Pointer_Main_String_Day_Names[Date.Day_Of_Week]);
	DisplayWriteCharacter(' ');
	// Display the day
	MainConvertBCDToASCII(Date.Day, &Tens_Character, &Units_Character);
	DisplayWriteCharacter(Tens_Character);
	DisplayWriteCharacter(Units_Character);
	DisplayWriteCharacter('/');
	// Display the month
	MainConvertBCDToASCII(Date.Month, &Tens_Character, &Units_Character);
	DisplayWriteCharacter(Tens_Character);
	DisplayWriteCharacter(Units_Character);
	DisplayWriteCharacter('/');
	// Display the year
	MainConvertBCDToASCII(Date.Year, &Tens_Character, &Units_Character);
	DisplayWriteCharacter('2');
	DisplayWriteCharacter('0');
	DisplayWriteCharacter(Tens_Character);
	DisplayWriteCharacter(Units_Character);
	
	// Clear temperature field last characters in case the previously displayed string was longer than the current one
	DisplaySetCursorLocation(DISPLAY_CURSOR_LOCATION_LINE_3 + 6);
	DisplayWriteString("  ");
	// Display temperature
	DisplaySetCursorLocation(DISPLAY_CURSOR_LOCATION_LINE_3 + 1);
	DisplayWriteString("T:");
	DisplayWriteNumber(Main_Current_Measures.Temperature);
	DisplayWriteString("\337C");
	
	// Clear pressure field last characters in case the previously displayed string was longer than the current one
	DisplaySetCursorLocation(DISPLAY_CURSOR_LOCATION_LINE_3 + 18);
	DisplayWriteCharacter(' ');
	// Display pressure
	DisplaySetCursorLocation(DISPLAY_CURSOR_LOCATION_LINE_3 + 9);
	DisplayWriteString("P:");
	DisplayWriteNumber(Main_Current_Measures.Pressure);
	DisplayWriteString("mbar");
	
	// Clear humidity field last character in case the previously displayed string was longer than the current one
	DisplaySetCursorLocation(DISPLAY_CURSOR_LOCATION_LINE_4 + 6);
	DisplayWriteString("  ");
	// Display humidity
	DisplaySetCursorLocation(DISPLAY_CURSOR_LOCATION_LINE_4 + 1);
	DisplayWriteString("H:");
	DisplayWriteNumber(Main_Current_Measures.Humidity);
	DisplayWriteCharacter('%');
	
	// Display alarm enabling state
	RTCGetAlarm(&Time_Alarm);
	DisplaySetCursorLocation(DISPLAY_CURSOR_LOCATION_LINE_4 + 9);
	if (ButtonsIsAlarmEnabled())
	{
		// Also display programmed alarm time
		DisplayWriteString("\002:ON(");
		
		// Hour
		MainConvertBCDToASCII(Time_Alarm.Hours, &Tens_Character, &Units_Character);
		DisplayWriteCharacter(Tens_Character);
		DisplayWriteCharacter(Units_Character);
		DisplayWriteCharacter(':');
		
		// Minutes
		MainConvertBCDToASCII(Time_Alarm.Minutes, &Tens_Character, &Units_Character);
		DisplayWriteCharacter(Tens_Character);
		DisplayWriteCharacter(Units_Character);
		DisplayWriteCharacter(')');
	}
	else DisplayWriteString("\002:OFF       "); // Add extra spaces to clear previous "ON" string
	
	// Is it time to ring ?
	
	if (ButtonsIsAlarmEnabled() && (Time.Hours == Time_Alarm.Hours) && (Time.Minutes == Time_Alarm.Minutes) && (Time.Seconds == 0x00))
	{
		RingStart();
		DisplayTurnBacklightOn(); // Also light display
	}
}

/** Display a menu allowing to choose which clock parameter to configure. */
static void MainShowConfigurationMenu(void)
{
	typedef enum
	{
		MENU_ID_SET_ALARM,
		MENU_ID_SET_TIME,
		MENU_ID_SET_DATE,
		MENU_ID_EXIT
	} TMenuID;
	TMenuID Selected_Menu_ID = MENU_ID_SET_ALARM;
	TRTCTime Time;
	TRTCDate Date;
	
	while (1)
	{
		// Display menu
		DisplayClear();
		// Set alarm
		if (Selected_Menu_ID == MENU_ID_SET_ALARM) DisplayWriteString("-> ");
		else DisplayWriteString("   ");
		DisplayWriteString("R\001gler alarme");
		// Set time
		DisplaySetCursorLocation(DISPLAY_CURSOR_LOCATION_LINE_2);
		if (Selected_Menu_ID == MENU_ID_SET_TIME) DisplayWriteString("-> ");
		else DisplayWriteString("   ");
		DisplayWriteString("R\001gler heure");
		// Set date
		DisplaySetCursorLocation(DISPLAY_CURSOR_LOCATION_LINE_3);
		if (Selected_Menu_ID == MENU_ID_SET_DATE) DisplayWriteString("-> ");
		else DisplayWriteString("   ");
		DisplayWriteString("R\001gler date");
		// Go back
		DisplaySetCursorLocation(DISPLAY_CURSOR_LOCATION_LINE_4);
		if (Selected_Menu_ID == MENU_ID_EXIT) DisplayWriteString("-> ");
		else DisplayWriteString("   ");
		DisplayWriteString("    Retour");
		
		// Handle buttons
		switch (ButtonsWaitMenuButtonPress())
		{
			// Select next menu entry
			case BUTTONS_MENU_ID_MINUS:
				if (Selected_Menu_ID == MENU_ID_EXIT) Selected_Menu_ID = MENU_ID_SET_ALARM; // Loop to menu first entry
				else Selected_Menu_ID++;
				break;
			
			// Select previous menu entry
			case BUTTONS_MENU_ID_PLUS:
				if (Selected_Menu_ID == MENU_ID_SET_ALARM) Selected_Menu_ID = MENU_ID_EXIT; // Loop to menu last entry
				else Selected_Menu_ID--;
				break;
				
			case BUTTONS_MENU_ID_SET:
				// Configure alarm
				if (Selected_Menu_ID == MENU_ID_SET_ALARM)
				{
					// Retrieve current alarm values
					RTCGetAlarm(&Time);
					Time.Hours = MainConvertBCDToBinary(Time.Hours);
					Time.Minutes = MainConvertBCDToBinary(Time.Minutes);
					
					// Configure hour
					Time.Hours = MainShowNumberSelectionView("--- HEURE ALARME ---", " Heure : ", 0, 23, Time.Hours);
					// Configure minutes
					Time.Minutes = MainShowNumberSelectionView("-- MINUTES ALARME --", " Minutes : ", 0, 59, Time.Minutes);
					
					// Configure RTC
					RTCSetAlarm(&Time);
				}
				// Configure time
				else if (Selected_Menu_ID == MENU_ID_SET_TIME)
				{
					// Retrieve current time values
					RTCGetTime(&Time);
					Time.Hours = MainConvertBCDToBinary(Time.Hours);
					Time.Minutes = MainConvertBCDToBinary(Time.Minutes);
					Time.Seconds = MainConvertBCDToBinary(Time.Seconds);
					
					// Configure hours
					Time.Hours = MainShowNumberSelectionView("--- REGLER HEURE ---", " Heure : ", 0, 23, Time.Hours);
					// Configure minutes
					Time.Minutes = MainShowNumberSelectionView("-- REGLER MINUTES --", " Minutes : ", 0, 59, Time.Minutes);
					// Configure seconds
					Time.Seconds = MainShowNumberSelectionView("- REGLER SECONDES --", " Secondes : ", 0, 59, Time.Seconds);
					
					// Configure RTC
					RTCSetTime(&Time);
				}
				// Configure date
				else if (Selected_Menu_ID == MENU_ID_SET_DATE)
				{
					// Retrieve current date values
					RTCGetDate(&Date);
					Date.Day = MainConvertBCDToBinary(Date.Day);
					Date.Month = MainConvertBCDToBinary(Date.Month);
					Date.Year = MainConvertBCDToBinary(Date.Year);
					
					// Configure day
					Date.Day = MainShowNumberSelectionView("--- REGLER JOUR ----", " Jour : ", 1, 31, Date.Day);
					// Configure month
					Date.Month = MainShowNumberSelectionView("--- REGLER MOIS ----", " Mois : ", 1, 12, Date.Month);
					// Configure year
					Date.Year = MainShowNumberSelectionView("--- REGLER ANNEE ---", " Ann\001e : 20", 20, 99, Date.Year);
					
					// Configure RTC
					RTCSetDate(&Date);
				}
				// Exit configuration menu
				else if (Selected_Menu_ID == MENU_ID_EXIT)
				{
					DisplayClear();
					return;
				}
				break;
		}
	}
}

/** Show minimum and maximum values of a specific measure.
 * @param Pointer_String_View_Title The measure name. It will be displayed on the first display line.
 * @param Pointer_String_Unit This string will be appended right after a measure value is displayed.
 * @param Minimum_Value Will be displayed after the text "minimum".
 * @param Maximum_Value Will be displayed after the text "maximum".
 */
static void MainShowMeasureValuesView(char *Pointer_String_View_Title, char *Pointer_String_Unit, signed short Minimum_Value, signed short Maximum_Value)
{
	// Display view title
	DisplayClear();
	DisplayWriteString(Pointer_String_View_Title);
	
	// Display minimum value
	DisplaySetCursorLocation(DISPLAY_CURSOR_LOCATION_LINE_2);
	DisplayWriteString("Minimum : ");
	DisplayWriteNumber(Minimum_Value);
	DisplayWriteString(Pointer_String_Unit);
	
	// Display maximum value
	DisplaySetCursorLocation(DISPLAY_CURSOR_LOCATION_LINE_3);
	DisplayWriteString("Maximum : ");
	DisplayWriteNumber(Maximum_Value);
	DisplayWriteString(Pointer_String_Unit);
}
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
void main(void)
{
	unsigned char Sensors_Measure_Seconds_Counter = 0;
	
	// Set oscillator frequency to 64MHz
	OSCCON = 0x78; // Core enters sleep mode when issuing a SLEEP instruction, select 16MHz frequency for high frequency internal oscillator, device is running from primary clock (set as "internal oscillator" in configuration registers)
	while (!OSCCONbits.HFIOFS); // Wait for the internal oscillator to stabilize
	OSCCON2 = 0x04; // Turn off secondary oscillator, enable primary oscillator drive circuit
	OSCTUNEbits.PLLEN = 1; // Enable 4x PLL
	
	// Initialize modules
	DisplayInitialize();
	RTCInitialize();
	if (SensorsInitialize() != 0)
	{
		DisplayWriteString("BME680 error.");
		DisplaySetCursorLocation(DISPLAY_CURSOR_LOCATION_LINE_2);
		DisplayWriteString("Please reboot.");
		while (1);
	}
	ButtonsInitialize();
	RingInitialize();
	
	// Enable interrupts
	RCONbits.IPEN = 1; // Enable interrupt priorities
	INTCONbits.GIE = 1; // Enable high priority interrupts
	INTCONbits.PEIE = 1; // Enable low priority interrupts
	
	// Main loop
	while (1)
	{
		// Wait for a new tick to begin
		while ((RTC_TICK_PIN == 0) && (BUTTONS_PIN_SET == BUTTONS_STATE_RELEASED) && (BUTTONS_PIN_PLUS == BUTTONS_STATE_RELEASED) && (BUTTONS_PIN_MINUS == BUTTONS_STATE_RELEASED)); // Stop waiting if a button is pressed
		
		// Sample values once and make them available to all views
		SensorsGetMeasures(&Main_Current_Measures);
		
		// Determine minimum values
		if (Main_Current_Measures.Temperature < Main_Minimum_Measures.Temperature) Main_Minimum_Measures.Temperature = Main_Current_Measures.Temperature;
		if (Main_Current_Measures.Pressure < Main_Minimum_Measures.Pressure) Main_Minimum_Measures.Pressure = Main_Current_Measures.Pressure;
		if (Main_Current_Measures.Humidity < Main_Minimum_Measures.Humidity) Main_Minimum_Measures.Humidity = Main_Current_Measures.Humidity;
		
		// Determine maximum values
		if (Main_Current_Measures.Temperature > Main_Maximum_Measures.Temperature) Main_Maximum_Measures.Temperature = Main_Current_Measures.Temperature;
		if (Main_Current_Measures.Pressure > Main_Maximum_Measures.Pressure) Main_Maximum_Measures.Pressure = Main_Current_Measures.Pressure;
		if (Main_Current_Measures.Humidity > Main_Maximum_Measures.Humidity) Main_Maximum_Measures.Humidity = Main_Current_Measures.Humidity;
		
		// Display configuration menu if "set" button is pressed
		if (BUTTONS_PIN_SET == BUTTONS_STATE_PRESSED)
		{
			MainShowConfigurationMenu();

			// Make sure all keys are released
			BUTTONS_WAIT_FOR_BUTTON_RELEASE(BUTTONS_PIN_SET);
			BUTTONS_WAIT_FOR_BUTTON_RELEASE(BUTTONS_PIN_PLUS);
			BUTTONS_WAIT_FOR_BUTTON_RELEASE(BUTTONS_PIN_MINUS);
		}
		// Display statistics views if "plus" or "minus" buttons are pressed
		else if ((BUTTONS_PIN_MINUS == BUTTONS_STATE_PRESSED) || (BUTTONS_PIN_PLUS == BUTTONS_STATE_PRESSED))
		{
			// Display first or last measures view according to pressed button
			if (BUTTONS_PIN_MINUS == BUTTONS_STATE_PRESSED) MainShowMeasuresView(0);
			else MainShowMeasuresView(1);
			
			// Make sure all keys are released
			BUTTONS_WAIT_FOR_BUTTON_RELEASE(BUTTONS_PIN_SET);
			BUTTONS_WAIT_FOR_BUTTON_RELEASE(BUTTONS_PIN_PLUS);
			BUTTONS_WAIT_FOR_BUTTON_RELEASE(BUTTONS_PIN_MINUS);
			
			// Clean any remaining trace
			DisplayClear();
		}
		
		// Always display time and date view, so they are immediately visible when exiting from configuration menu
		MainShowDefaultView();
		
		// Trigger measures each 2 seconds
		Sensors_Measure_Seconds_Counter++;
		if (Sensors_Measure_Seconds_Counter == 2)
		{
			SensorsStartMeasurement();
			Sensors_Measure_Seconds_Counter = 0;
		}
		
		// Wait for tick end
		while ((RTC_TICK_PIN == 1) && (BUTTONS_PIN_SET == BUTTONS_STATE_RELEASED) && (BUTTONS_PIN_PLUS == BUTTONS_STATE_RELEASED) && (BUTTONS_PIN_MINUS == BUTTONS_STATE_RELEASED)); // Stop waiting if a button is pressed
	}
}

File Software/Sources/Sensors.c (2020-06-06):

/** @file Sensors.c
 * See Sensors.h for description.
 * @author Adrien RICCIARDI
 */
#include <bme680.h>
#include <Sensors.h>
#include <xc.h>

//-------------------------------------------------------------------------------------------------
// Private constants and macros
//-------------------------------------------------------------------------------------------------
/** Set chip /SS to low level (hold time must be at least 20ns, so no need to add delay with an instruction clock of 62.5ns). */
#define SENSORS_SELECT_DEVICE() LATCbits.LATC6 = 0

/** Set chip /SS to high level (hold time must be at least 20ns, so no need to add delay with an instruction clock of 62.5ns). */
#define SENSORS_UNSELECT_DEVICE() LATCbits.LATC6 = 1

//-------------------------------------------------------------------------------------------------
// Private variables
//-------------------------------------------------------------------------------------------------
/** The device, made available to all this module functions */
static struct bme680_dev Sensors_BME680_Device;

//-------------------------------------------------------------------------------------------------
// Private functions
//-------------------------------------------------------------------------------------------------
/** Transfer a byte on the SPI bus.
 * @param Byte The byte to transmit.
 * @return The byte received from the device.
 */
static inline unsigned char SensorsTransferSPIByte(unsigned char Byte)
{
	// Start transfer
	SSP1BUF = Byte;
	
	// Wait for transfer end
	while (!PIR1bits.SSP1IF);
	PIR1bits.SSP1IF = 0; // Reset interrupt flag
	
	// Interrupt flag is set too soon (in the middle of the last clock pulse), so wait a full period (= 1/4MHz) to be sure transmission has finished
	asm("nop\n");
	asm("nop\n");
	asm("nop\n");
	asm("nop\n");
	asm("nop\n"); // Add a little margin
	
	// Get byte received from device
	return SSP1BUF;
}

/** Callback function called by BME680 library when it needs to wait some milliseconds.
 * @param Period How many milliseconds to wait.
 */
static void BME680DelayMilliseconds(unsigned long Period)
{
	while (Period > 0)
	{
		__delay_ms(1);
		Period--;
	}
}

/** Callback function called by BME680 library to read register values.
 * @param Device_ID Unused here.
 * @param Register_Address The base register targeted by the read command.
 * @param Pointer_Register_Data The data to read from the register and from the ones that follow.
 * @param Data_Bytes_Count How many payload bytes to read.
 * @return Always 0, this function can't fail.
 */
signed char BME680SPIRead(unsigned char __attribute__((unused)) Device_ID, unsigned char Register_Address, unsigned char *Pointer_Register_Data, unsigned short Data_Bytes_Count)
{
	SENSORS_SELECT_DEVICE();
	
	// Send register address
	SensorsTransferSPIByte(Register_Address | 0x80); // Bit 7 must be set to 1 to tell that this is a reading request
	
	// Read all requested bytes
	while (Data_Bytes_Count > 0)
	{
		*Pointer_Register_Data = SensorsTransferSPIByte(0);
		Pointer_Register_Data++;
		Data_Bytes_Count--;
	}
	
	SENSORS_UNSELECT_DEVICE();
	return 0;
}

/** Callback function called by BME680 library to write register values.
 * @param Device_ID Unused here.
 * @param Register_Address The base register targeted by the write command.
 * @param Pointer_Register_Data The data to write to the register and to the ones that follow.
 * @param Data_Bytes_Count How many payload bytes to write.
 * @return Always 0, this function can't fail.
 */
signed char BME680SPIWrite(unsigned char __attribute__((unused)) Device_ID, unsigned char Register_Address, unsigned char *Pointer_Register_Data, unsigned short Data_Bytes_Count)
{
	SENSORS_SELECT_DEVICE();
	
	// Send register address
	SensorsTransferSPIByte(Register_Address & 0x7F); // Bit 7 must be set to 0 to tell that this is a writing request
	
	// Write all requested bytes
	while (Data_Bytes_Count > 0)
	{
		SensorsTransferSPIByte(*Pointer_Register_Data);
		Pointer_Register_Data++;
		Data_Bytes_Count--;
	}
	
	SENSORS_UNSELECT_DEVICE();
	return 0;
}

//--------------------------------------------------------------------------------------------------
// Public functions
//--------------------------------------------------------------------------------------------------
unsigned char SensorsInitialize(void)
{
	// Configure pins
	// Set all pins to digital
	ANSELC &= 0x87;
	// Configure pins direction
	TRISCbits.TRISC3 = 0; // SCK pin
	TRISCbits.TRISC4 = 1; // SDI pin
	TRISCbits.TRISC5 = 0; // SDO pin
	SENSORS_UNSELECT_DEVICE();
	TRISCbits.TRISC6 = 0; // /SS pin
	
	// Configure MSSP1 for SPI master operation
	SSP1STAT = 0; // Sample input data at middle of data output time, transmit on transition from idle to active clock state
	SSP1CON1 = 0x31; // Enable SPI module, set SPI clock idle state to high, select SPI master mode with Fosc/16 = 4MHz clock
	
	// Probe sensor and load internal calibration settings
	Sensors_BME680_Device.dev_id = 0;
	Sensors_BME680_Device.intf = BME680_SPI_INTF;
	Sensors_BME680_Device.read = BME680SPIRead;
	Sensors_BME680_Device.write = BME680SPIWrite;
	Sensors_BME680_Device.delay_ms = BME680DelayMilliseconds;
	Sensors_BME680_Device.amb_temp = 25;
	if (bme680_init(&Sensors_BME680_Device) != BME680_OK) return 1;
	
	// Configure sensor settings
	// Set humidity oversampling
	Sensors_BME680_Device.tph_sett.os_hum = BME680_OS_8X; // Use an high oversampling value to get more precise measures
	// Set pressure oversampling
	Sensors_BME680_Device.tph_sett.os_pres = BME680_OS_4X; // Use 4x oversampling
	// Set temperature oversampling
	Sensors_BME680_Device.tph_sett.os_temp = BME680_OS_2X; // Use 2x oversampling
	// Configure low pass digital filter that is available for temperature and pressure data
	Sensors_BME680_Device.tph_sett.filter = BME680_FILTER_SIZE_3; // Enable IIR filter with a coefficient of 3
	// Disable gas sensor for now
	Sensors_BME680_Device.gas_sett.run_gas = BME680_DISABLE_GAS_MEAS;
	
	// Turn sensor on (this must be set before writing the sensor configuration)
	Sensors_BME680_Device.power_mode = BME680_FORCED_MODE;

	// Set the desired sensor configuration
	if (bme680_set_sensor_settings(BME680_OST_SEL | BME680_OSP_SEL | BME680_OSH_SEL | BME680_FILTER_SEL | BME680_GAS_SENSOR_SEL, &Sensors_BME680_Device) != BME680_OK) return 1;

	// Trigger first measure
	SensorsStartMeasurement();
	
	return 0;
}

void SensorsStartMeasurement(void)
{
	bme680_set_sensor_mode(&Sensors_BME680_Device);
}

void SensorsGetMeasures(TSensorsMeasures *Pointer_Measures)
{
	struct bme680_field_data Data;
	
	// Retrieve latest data
	bme680_get_sensor_data(&Data, &Sensors_BME680_Device);
	
	// Convert them to requested scales
	Pointer_Measures->Temperature = Data.temperature / 100; // Convert to Celsius degrees
	Pointer_Measures->Pressure = Data.pressure / 100; // Convert to millibar
	Pointer_Measures->Humidity = Data.humidity / 1000; // Convert to percentage
	// TODO convert air quality
}

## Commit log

2020-03-24 [Hardware] Started schematic. Added BME680 sensor and RTC.
    [FTDI.sch, Motherboard.kicad_pcb, Motherboard.sch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]
2020-03-24 [Hardware] Added RTC battery and Adafruit BME680 board.
    [FTDI.sch, Motherboard.kicad_pcb, Motherboard.sch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]
2020-03-24 [Hardware] Replaced PIC18F26K22 microcontroller by PIC18F46K22 to have more pins.
    [Motherboard.kicad_pcb, Motherboard.sch, Sensors_RTC.sch]
2020-03-24 [Hardware] Added display support.
    [Display.sch, FTDI.sch, Motherboard.sch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]
2020-03-25 [Hardware] Added buttons.
    [Display.sch, FTDI.sch, Motherboard.kicad_pcb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]
2020-03-25 [Hardware] Added simpler buttons debouncing and also added debouncing to buttons that trigger an interrupt.
    [Display.sch, Motherboard.sch, Sensors_RTC.sch]
2020-03-25 [Hardware] Added all schematic parts (but not all external parts, like display or female connectors).
    [Display.sch, Motherboard.kicad_pcb, Motherboard.sch]
2020-03-25 [Hardware] Started PCB routing. Components are placed, BME680 board mounting holes are in position, some nets are connected.
    [Display.sch, Motherboard.kicad_pcb, Motherboard.sch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]
2020-03-26 [Hardware] Moved buttons to another schematic sheet and fully routed PCB.
    [Buttons.sch, Display.sch, Motherboard.kicad_pcb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]
2020-03-26 [Hardware] Used a custom empty footprint for Adafruit module part. This way, part is visible in schematic and bill of materials, but it is not part of the PCB.
    [Motherboard.kicad_pcb, Sensors_RTC.sch]
2020-03-26 [Hardware] Added display part in both schematic and PCB.
    [Display.sch, Motherboard.kicad_pcb]
2020-03-26 [Hardware] Swapped programming connector to have it in the right order.
    [Motherboard.kicad_pcb, Motherboard.sch]
2020-03-26 [Hardware] Displayed project date on PCB.
    [Motherboard.kicad_pcb]
2020-03-26 [Hardware] Added alarm and backlight buttons parts to both schematic and PCB.
    [Buttons.sch, Motherboard.kicad_pcb]
2020-03-26 [Hardware] Removed KiCad cache file from repository.
2020-03-27 [Hardware] Added USB connector supply part to both schematic and PCB.
    [Motherboard.kicad_pcb, Motherboard.sch]
2020-03-27 [Hardware] Renamed LCD display symbol for more coherency.
    [Display.sch, Motherboard.kicad_pcb]
2020-04-18 [Hardware] Slightly decreased PCB width and adjusted it to millimeters.
    [Motherboard.kicad_pcb]
2020-04-18 Added more KiCad temporary files to .gitignore.
2020-04-18 [Hardware] Slightly decreased PCB height and adjusted it to millimeters.
    [Motherboard.kicad_pcb]
2020-04-18 [Hardware] Moved PCB mounting holes to fit new board dimensions.
    [Motherboard.kicad_pcb]
2020-04-18 [Hardware] Added PCB switches 3D model.
    [Motherboard.kicad_pcb]
2020-04-18 [Hardware] Filled some empty bottom layer areas with ground plane.
    [Motherboard.kicad_pcb]
2020-04-19 [Hardware] Displayed connectors usage and button names on PCB.
    [Motherboard.kicad_pcb]
2020-04-21 [Hardware] Replaced each supply part by a generic one to avoid creating a new symbol for every supply part.
    [Buttons.sch, Display.sch, Motherboard.kicad_pcb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]
2020-04-24 [Software] Started firmware implementation. Configured microcontroller fuses and added a basic test that blinks the display background.
2020-04-24 [Software] Started display driver. Display initialization works and a test text is displayed.
2020-04-24 [Software] Enabled 1Hz square-wave generation by RTC.
2020-04-25 [Software] Started BME680 sensor driver. It is able to read the chip ID.
2020-04-26 [Software] Added configuration buttons support and a test configuration menu view.
2020-04-26 [Software] Used BME680 library provided by sensor manufacturer. Switched C standard to C99 to be able to build this library.
2020-04-26 [Software] Retrieved pressure and humidity from BME680 sensor and displayed them.
2020-04-26 [Software] Disabled BME680 gas sensor for now as air quality computations seem hard to find.
2020-04-27 [Software] Added buttons support to configuration menu view.
2020-04-27 [Software] Moved menu buttons related functions to a dedicated module.
2020-04-28 [Software] Avoided out-of-range values to be displayed by number selection view.
    [Main.c]
2020-04-28 [Software] Inverted 'plus' and 'minus' buttons to make them match PCB marking.
    [Menu_Buttons.h]
2020-04-28 [Software] Added backlight button support.
2020-04-29 [Software] Renamed 'Menu_Button' module in 'Buttons', so it can also handle alarm and backlight buttons.
2020-04-29 [Software] Moved backlight button code to 'Buttons' module.
2020-04-29 [Hardware] Swapped 'plus' and 'minus' buttons in both schematic and PCB to match final buttons position.
    [Buttons.sch, Motherboard.kicad_pcb, Motherboard.sch]
2020-04-29 [Software] Inverted 'plus' and 'minus' buttons behavior in configuration menu view to make the menu feel more intuitive.
    [Main.c]
2020-04-29 [Resources] Added PCB and display pictures.
2020-05-01 [Resources] Added mini USB connector datasheet.
2020-05-02 [Software] Set default date, time and alarm when RTC data are corrupted to avoid displaying impossible values.
    [RTC.c]
2020-05-04 [Casing] Started casing design. Added bottom face.
    [Casing.dxf]
2020-05-08 [Casing] Added remaining faces. Construction lines are still present.
    [Casing.dxf]
2020-05-08 [Casing] Removed construction lines.
    [Casing.dxf]
2020-05-15 [Resources] Added casing steel plates picture.
2020-05-28 [Software] Added views to display minimum and maximum values for temperature, pression and humidity.
2020-05-28 [Software] Discarded Celsius degree character hack now that XC8 2.20 is able to correctly parse escaped characters.
    [Main.c]
2020-06-17 [Software] Fixed a bug : an alarm hour greater than 19 could not be set.
    [RTC.c]
